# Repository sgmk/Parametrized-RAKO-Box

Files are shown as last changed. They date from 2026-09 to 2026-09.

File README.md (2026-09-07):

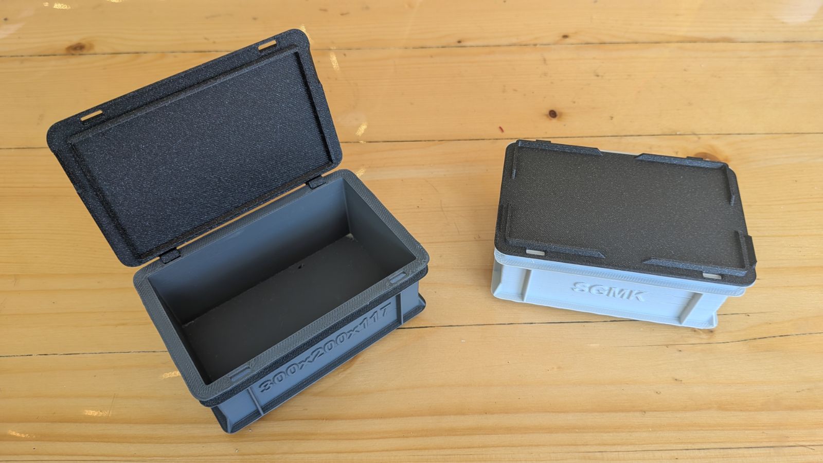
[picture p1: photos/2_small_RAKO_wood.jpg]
Printed Box with Wood Lid


# Parametrized RAKO Box (Eurobox / Stapelbehälter)
A highly customizable, 3D-printable OpenSCAD model of the classic Utz RAKO Eurobox (Stapelbehälter).

This repository contains a fully parametric, printable model that mathematically replicates the complex draft-tapered geometry, structural rims, and stacking feet of a real RAKO box, allowing you to print custom storage solutions that perfectly interlock with industry standards.

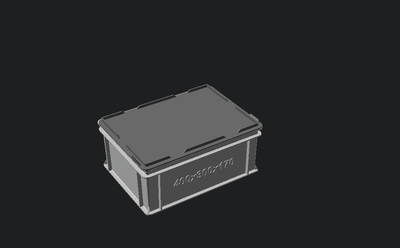
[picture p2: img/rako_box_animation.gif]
Animated Rako Box


## 📖 History of this Project
This project started as an experiment in human-AI collaboration during the [ddoS (das dreitägige odenwilusenz Sommerfest) event](https://ddos.odenwilusenz.ch/Hauptseite) late at night. The goal was to collaborate with an AI assistant to reverse-engineer and parametrically design a highly complex, 3D-printable replica of the classic Utz RAKO Eurobox.

Using a combination of reference photos, official Utz technical catalogs, and even audio messages to describe the intricate physical details (like the continuous draft taper, horizontal rims, and corner gussets), we iteratively refined the model. The entire geometry was coded from scratch in **OpenSCAD**, guided by continuous back-and-forth feedback with **Gemini AI**. Over the course of the night, we went from struggling with basic proportions to mathematically deriving a robust, parametric, support-free printing framework that accurately replicates the authentic industrial design.

## 📸 Gallery
### Real Prints
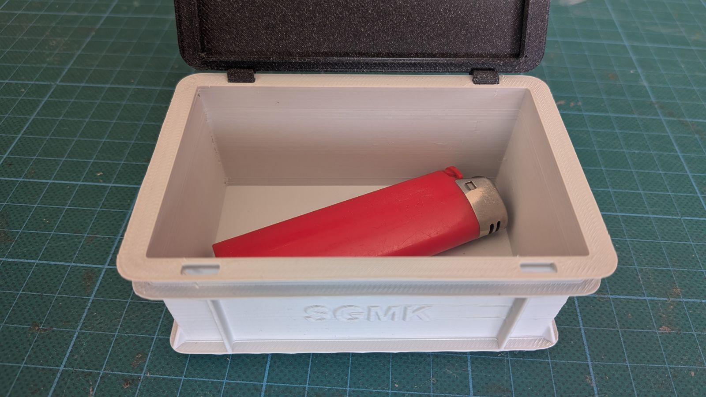
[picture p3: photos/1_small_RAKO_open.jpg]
Printed Box Open

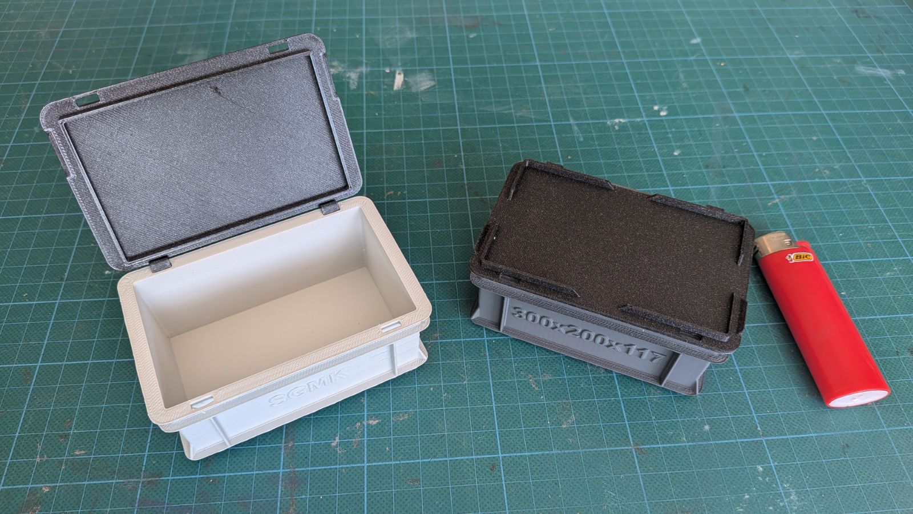
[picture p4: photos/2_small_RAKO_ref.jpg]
Printed Box Reference


### Technical Drawings
*The structural complexity of the RAKO system is derived from its continuous draft taper and nested inset tiers. The outer shell, inner ribs, and bottom stacking foot each reside on precise inward-leaning planes to ensure immense rigidity while allowing identical boxes to interlock seamlessly with a perfect 1mm tolerance. Note that while this model replicates the authentic stacking geometry, the exact wall thicknesses and rib dimensions have been optimized for FDM 3D printing and structural stability, rather than being a 1:1 identical copy of the original injection-molded box.*

<p align="center">
  Overall Cross-Section
  Detailed Wall Cross-Section
</p>

### OpenSCAD Customizer Renders
*(Large size presets shown with Snap-on Lids)*
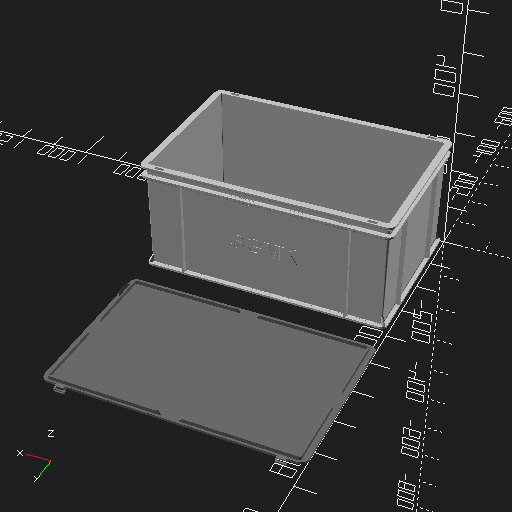
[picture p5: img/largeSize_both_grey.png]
Large Size


## 🆕 What's New in V5
* **Living-Hinge Snap Clips**: The lid now features flexible drop-down snap clips that mechanically lock into the existing side zip-tie holes of the box. The thickness of the clip dynamically calculates to fill the hole depth perfectly for a snug fit.
* **Independent Lid Thickness**: The lid plate thickness has been decoupled from the main wall thickness, allowing you to make much thicker, more robust lids without having to unnecessarily bulk up the box walls.
* **Refined Bash Exporting**: Included bash script now perfectly batch exports standard configurations, completely stripping OpenSCAD parameter overrides.

## ✨ Features
* **Standard & Custom Sizes**: Use the built-in dropdowns to instantly select all standard Utz RAKO footprint sizes (200x150, 300x200, 400x300, 600x400, 800x600) and standard heights, or disable it to enter fully custom L x W x H bounds.
* **Mathematical Stacking**: The model automatically calculates wall thicknesses and dynamic inset steps to guarantee a perfect 1.0mm clearance stacking fit. The boxes will interlock tightly with each other and with real commercial Euroboxes.
* **Support-Free Printing**: The top rims feature parametric diagonal support triangles and massive corner gussets tuned to a standard 50° overhang, allowing you to print the complex upper structural flanges entirely without slicer supports.
* **Snap-Fit Lid & Hinges**: Optional snap-fit interlocking lids, including deep hinge slots on the back edge to attach C-hinges without losing the beautifully rounded corners.
* **Custom Embossing**: Easily emboss your own text labels onto the front and back long sides of the box using any font installed on your system.

## 🖨️ 3D Printing Tips
* **Support Triangles**: Real Utz RAKO boxes don't have small triangular supports under the top rim. However, because FDM 3D printers struggle with aggressive 90-degree overhangs, this parametric model introduces optional support triangles. Leave these enabled in the Customizer to allow the box to print cleanly without needing any slicer-generated support material!
* **Bottom Rim Supports**: While the top rims print support-free, it is highly recommended to enable standard slicer supports for the absolute bottom stacking foot/rim. These supports are very easy to remove and ensure the underside prints with perfect dimensional accuracy, guaranteeing the foot clicks cleanly inside the box below it when stacked.

<p align="center">
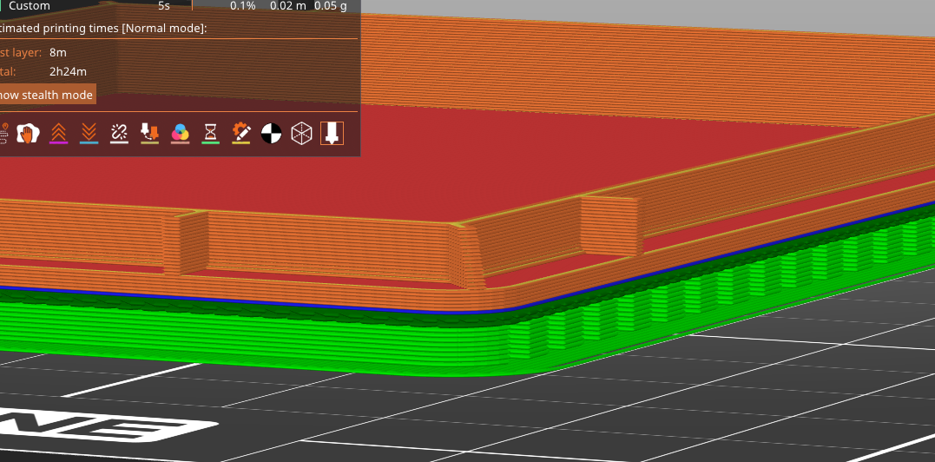
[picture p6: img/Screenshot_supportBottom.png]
Bottom Supports in Slicer
  
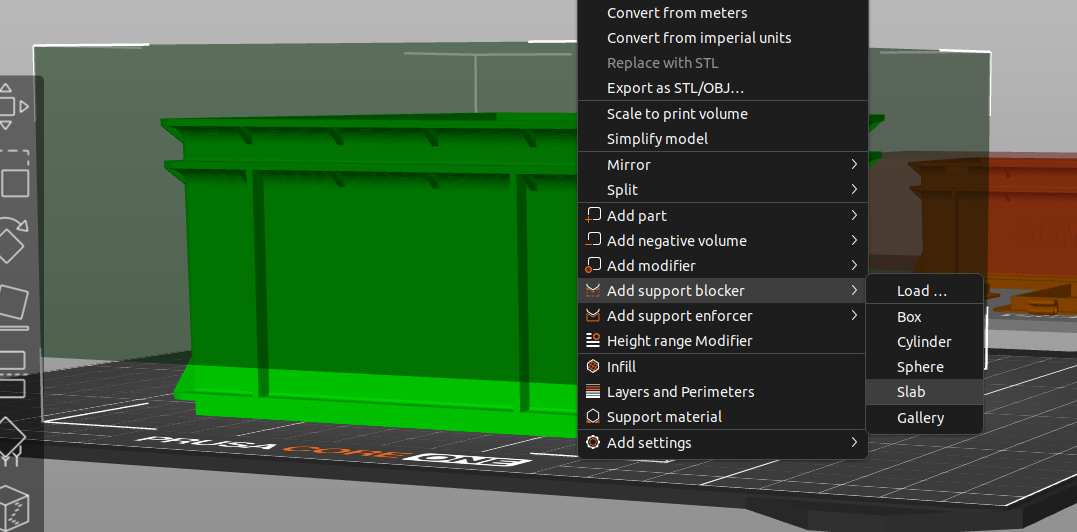
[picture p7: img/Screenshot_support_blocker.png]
Support Blocker in Slicer
  
</p>

* **Support Blockers**: To ensure your slicer only generates supports for the bottom rim and doesn't accidentally try to support the embossed text or the upper support-free rims, add a large support blocker volume (cube) covering the entire upper half of the box.

* **Scaling the Model**: The OpenSCAD design is scaled 1:1 to the exact size and proportions of commercial RAKO boxes. However, **we strongly advise against printing them at full scale!** Printing a full-size RAKO box is an immense waste of time, energy, and PLA—if you need a full-size box, it makes much more sense for the environment (and your wallet) to just buy a real injection-molded one! Instead, this model is meant to be scaled down in your slicer to create perfect miniature organizers. Scaling the generated STLs down to **33%** in your slicer is the sweet spot. At 33%, the snap-fit hinges still function perfectly. You can scale them down to **25%** because they look incredibly cute, but be warned that the hinges will be at the absolute limit of their mechanical stability and may become too fragile!

## 🚀 Usage
1. Place both `rako_box_V5.scad` and the accompanying `rako_box_V5.json` presets file in the same folder.
2. Open the `.scad` file in **OpenSCAD**.
3. Ensure the Customizer is visible (View -> Customizer).
4. Use the dropdowns to configure your box, or select one of the pre-configured presets from the top dropdown (smallSize, midSize, largeSize, BrushologyBox).
5. Render (`F6`) and Export to STL!

### Automated Exporting & Scaling
We have included a handy bash script (`export_stls.sh`) to automatically generate all STLs (the main boxes and the split lids) for the standard presets in one go.

To export everything at 1:1 full scale:
```bash
bash export_stls.sh
```

**Targeting a Single Preset:**
If you only want to export a specific preset, you can pass its name as the second argument (after the scale factor).
For example, to export only the `BrushologyBox` at 1:1 scale:
```bash
bash export_stls.sh 1.0 BrushologyBox
```

**Auto-Scaling for Miniatures:**
Because we strongly recommend printing miniatures, the script supports an optional scale parameter. It will automatically pass this to OpenSCAD and append the scale to the output filenames, so your 1:1 scale STLs are never accidentally overwritten!

For example, to export all presets pre-scaled to 33%:
```bash
bash export_stls.sh 0.33
```
Or to export *only* the `smallSize` preset at 50%:
```bash
bash export_stls.sh 0.5 smallSize
```
This will generate neatly named files like `STLs/smallSize/smallSize_V5_box_scale0.5.stl`.

*(Note: If you save a new custom preset in the Customizer (for example, named `myCustomBox`), you can simply run `bash export_stls.sh 1.0 myCustomBox` and the script will automatically export it for you!)*

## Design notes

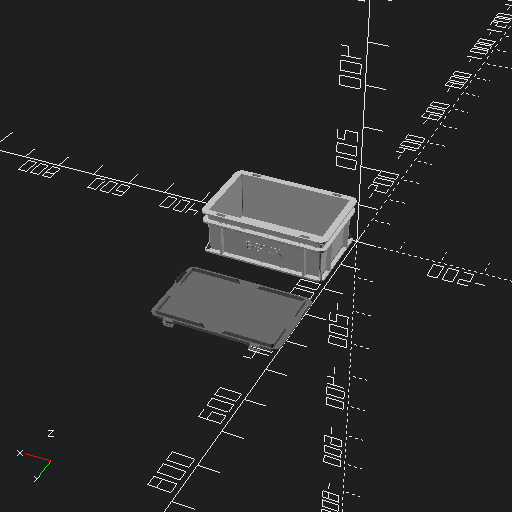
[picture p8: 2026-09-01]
img/smallSize_both_grey.png

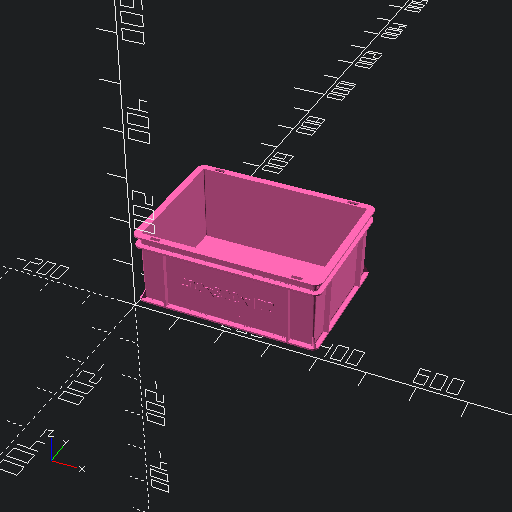
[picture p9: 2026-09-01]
img/midSize.png

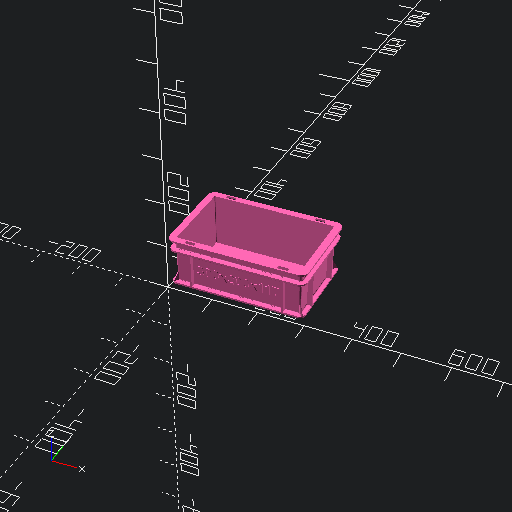
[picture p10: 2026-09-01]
img/smallSize.png

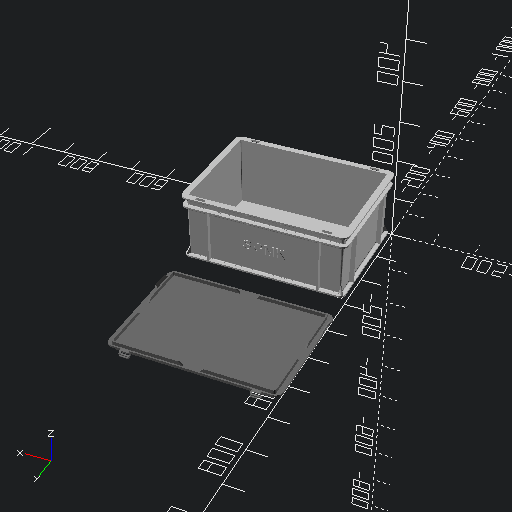
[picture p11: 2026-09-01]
img/midSize_both_grey.png

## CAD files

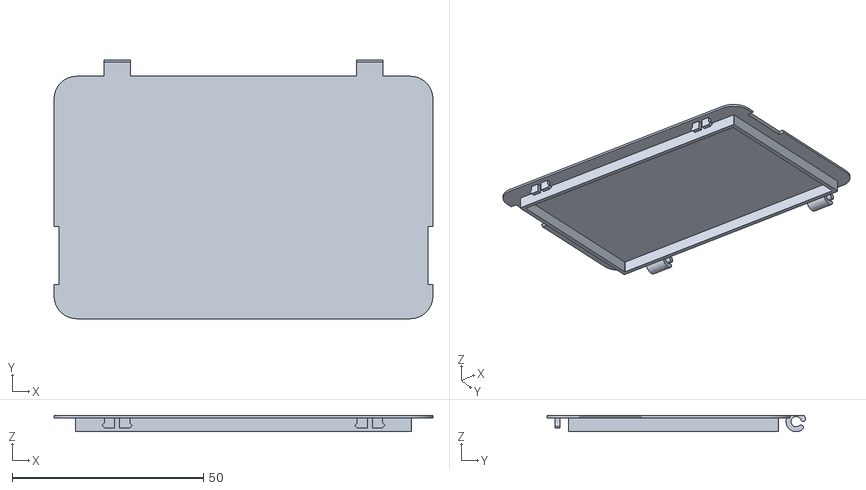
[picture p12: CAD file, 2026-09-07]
STL-Ready4Print/V5/BrushologyBox/BrushologyBox_V5_lid_lower_scale0.33.stl
99.0 x 67.5 x 4.29

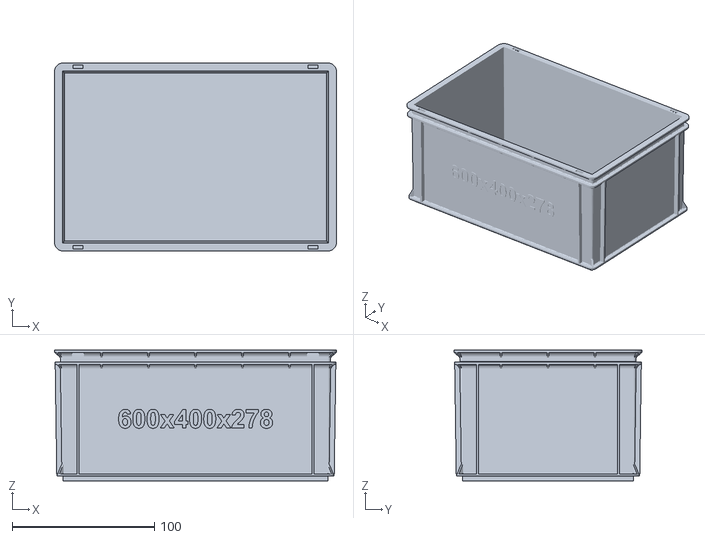
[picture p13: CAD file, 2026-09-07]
STL-Ready4Print/V5/largeSize/largeSize_V5_box_scale0.33.stl
198.0 x 132.0 x 91.7

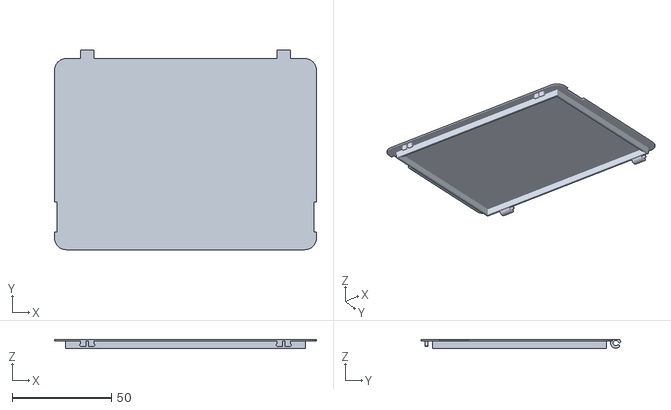
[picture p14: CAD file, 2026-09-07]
STL-Ready4Print/V5/midSize/midSize_V5_lid_lower_scale0.33.stl
132.0 x 100.5 x 4.29

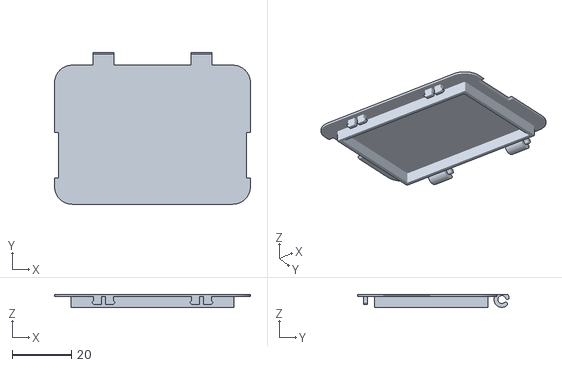
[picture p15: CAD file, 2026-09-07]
STL-Ready4Print/V5/miniSize/miniSize_V5_lid_lower_scale0.33.stl
66.0 x 51.0 x 4.29

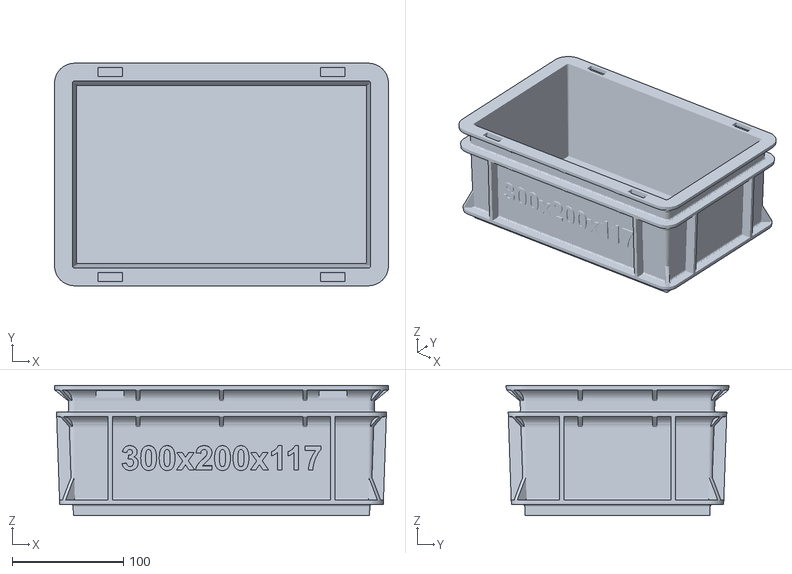
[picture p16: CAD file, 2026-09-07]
STL-Ready4Print/V5/smallSize/smallSize_V5_box.stl
300.0 x 200.0 x 117.0

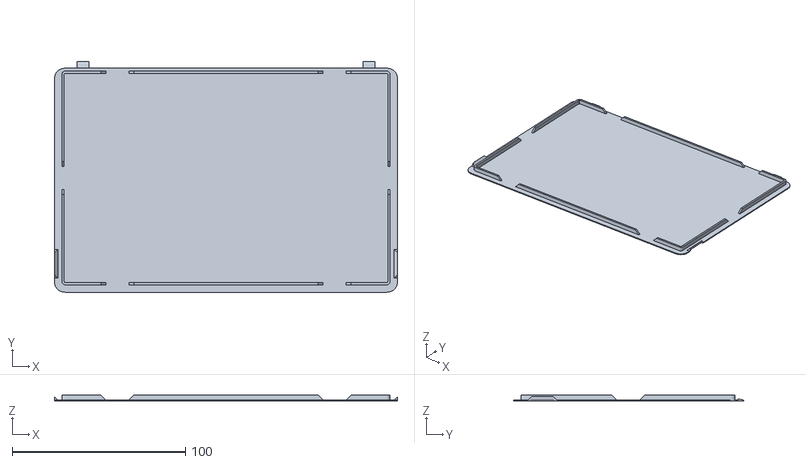
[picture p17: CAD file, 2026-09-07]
STL-Ready4Print/V5/largeSize/largeSize_V5_lid_upper_scale0.33.stl
198.0 x 133.1 x 3.63

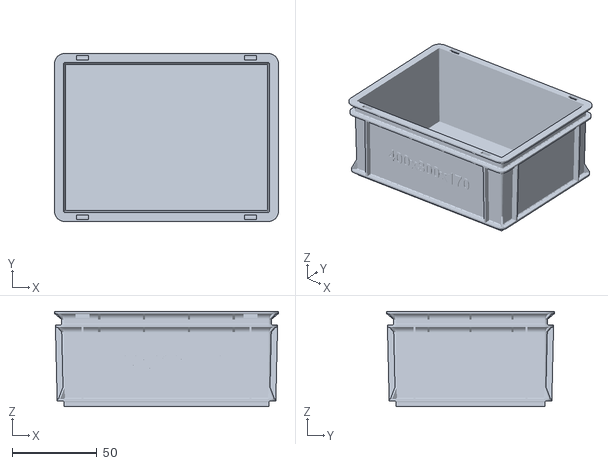
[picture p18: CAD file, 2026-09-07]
STL-Ready4Print/V5/midSize/midSize_V5_box_scale0.33.stl
132.0 x 99.0 x 56.1

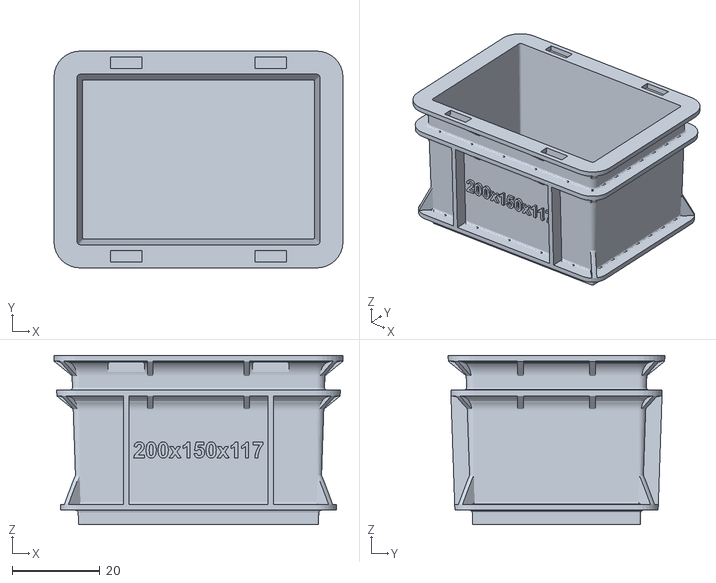
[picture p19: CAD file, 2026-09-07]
STL-Ready4Print/V5/miniSize/miniSize_V5_box_scale0.33.stl
66.0 x 49.5 x 38.6

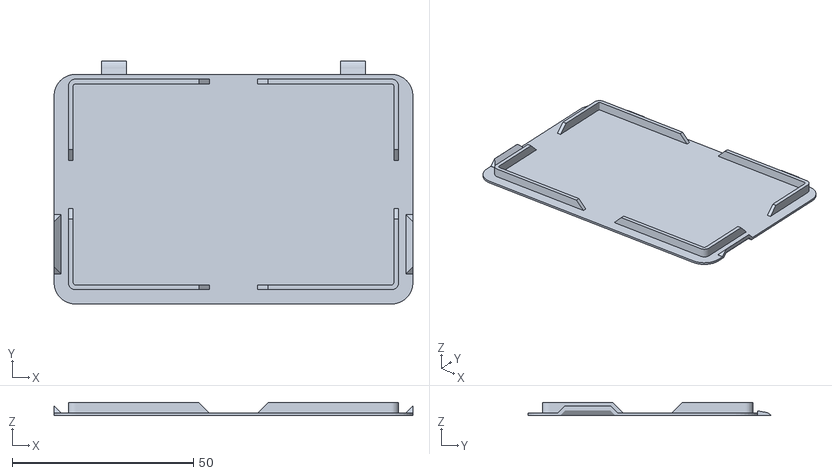
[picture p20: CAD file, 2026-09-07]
STL-Ready4Print/V5/smallSize/smallSize_V5_lid_upper_scale0.33.stl
99.0 x 67.1 x 3.63

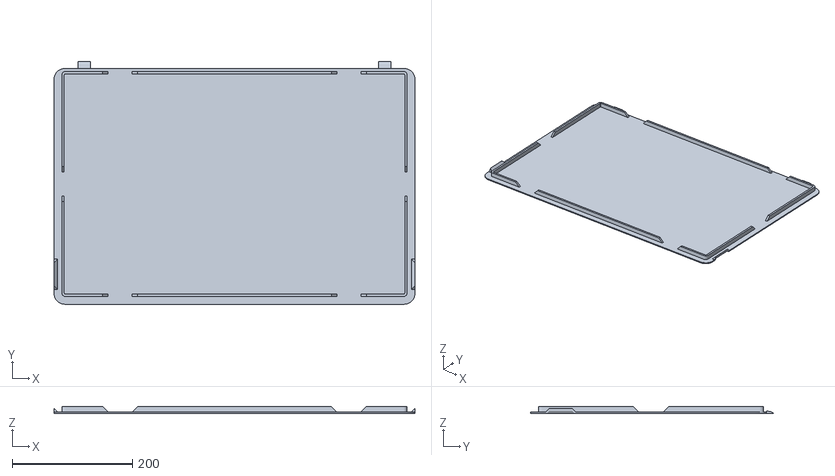
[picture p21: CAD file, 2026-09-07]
STL-Ready4Print/V5/largeSize/largeSize_V5_lid_upper.stl
600.0 x 403.2 x 11.0

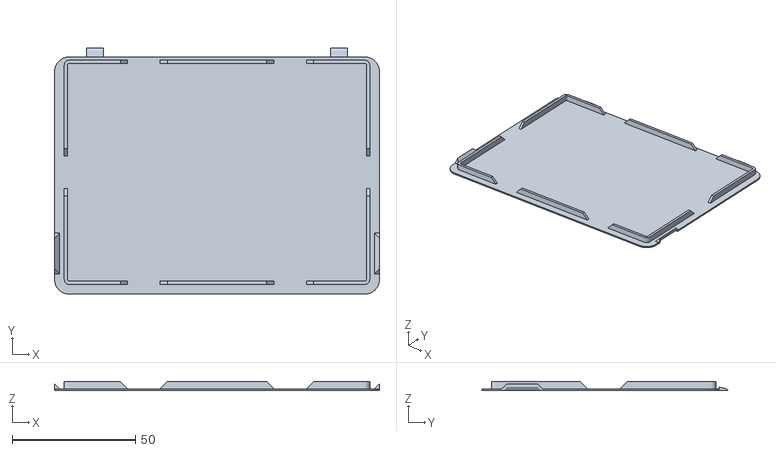
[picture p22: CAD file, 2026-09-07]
STL-Ready4Print/V5/midSize/midSize_V5_lid_upper_scale0.33.stl
132.0 x 100.1 x 3.63

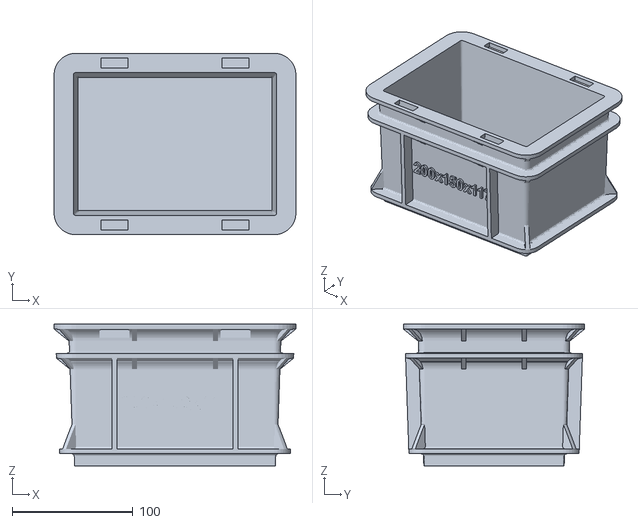
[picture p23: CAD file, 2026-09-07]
STL-Ready4Print/V5/miniSize/miniSize_V5_box.stl
200.0 x 150.0 x 117.0

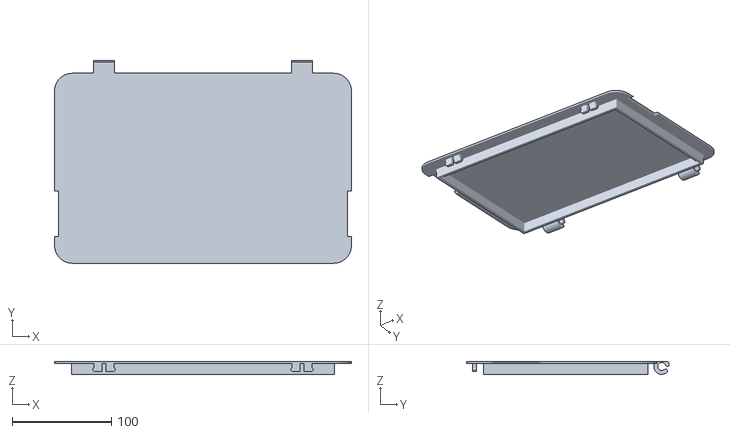
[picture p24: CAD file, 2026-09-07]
STL-Ready4Print/V5/smallSize/smallSize_V5_lid_lower.stl
300.0 x 204.6 x 13.0

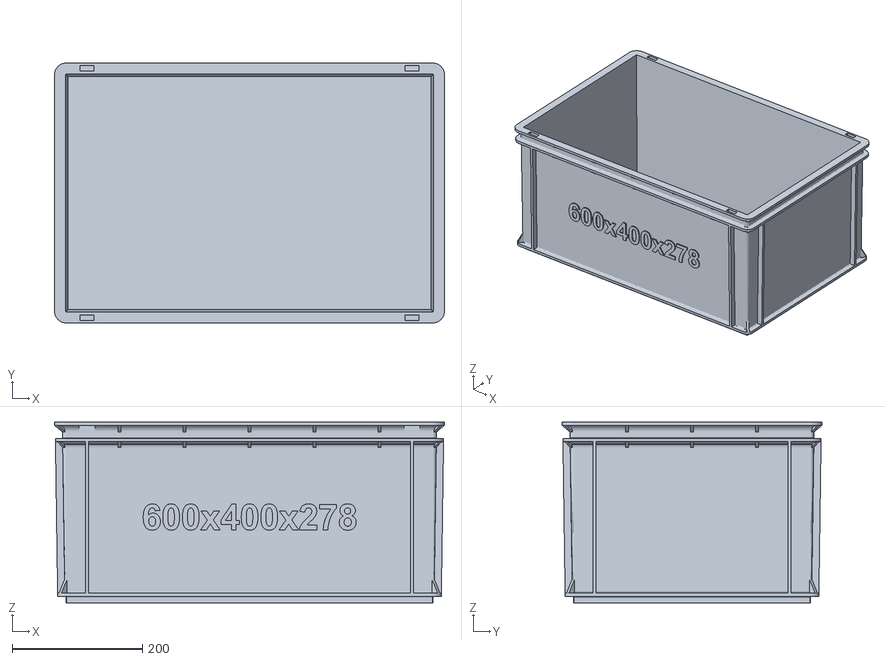
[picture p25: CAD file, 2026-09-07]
STL-Ready4Print/V5/largeSize/largeSize_V5_box.stl
600.0 x 400.0 x 278.0

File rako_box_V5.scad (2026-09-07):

// Parametric Rako Box (Eurobox) - Simplified Edition
// Accurately models the Utz frame construction with a continuous draft angle
// Units in mm
//
// Standard Rako / Eurobox Base Dimensions (L x W):
// - 200 x 150 mm
// - 300 x 200 mm
// - 400 x 300 mm
// - 600 x 400 mm
// - 800 x 600 mm
// 
// Standard Heights (H):
// - 65, 117, 145, 170, 220, 278, 325, 425 mm

// --- User Parameters ---

/* [Render Options] */
// Which part to render
part = "box"; // ["box", "lid", "lid_upper", "lid_lower", "both", "assemble"]
// Height at which to split the lid for 3D printing (creates lid_upper and lid_lower)
lid_split_z = 2.0;

/* [Global Dimensions] */
// Use standard Rako dimensions or custom values below
use_standard_dimensions = true;

// Standard Base Size (L x W)
standard_base = "400x300"; // ["200x150", "300x200", "400x300", "600x400", "800x600"]
// Standard Height
standard_height = 170; // [65, 117, 145, 170, 220, 278, 325, 425]
// Master thickness for all structural rims, flanges, ribs, and main walls
rim_width = 4.0; // [0.1:0.1:8.00]
// Thickness of the main drafted skin walls
wall_thickness = 4.0; // [0.1:0.1:8.00]
// Thickness of the main flat lid plate (wall thickness of the lid)
lid_plate_thickness = 4.0; // [0.1:0.1:8.00]
// Add snap-on C-hinges to the back edge
add_hinges = true;
// Enable the lid closure slots in the top rim
enable_closing_holes = true;

/* [Lid Snap-Fit] */
// Enable mechanical snap-on clips for the lid
add_snap_clips = true;
// Clearance gap between the arm and the box hole
snap_clip_tolerance = 2.0;

/* [Custom Dimensions] */
// (These are only used if 'use_standard_dimensions' is unchecked)
custom_length = 300;
// Custom Width
custom_width = 200;
// Custom Height
custom_height = 117;

/* [3D-Printing Features] */
// Number of small triangular supports evenly spaced under the top rim per side
support_triangles = 4; // [0:10]
// Add corner triangular supports under the top rim
support_corners = true;
// 3D Printing Overhang Angle for the supports (from vertical Z-axis). Higher is a shallower slope, easier to print.
support_angle = 50.0; // [30:70]

/* [Text Options] */
// Text embossed on the front long side
text_front = "400x300x170";
// Text embossed on the back long side
text_back = "SGMK";
// Font style for the text
text_font = "Arial:style=Bold";
// Font size
text_size = 25.0;
// Horizontal offset for the text (moves left/right)
text_x_offset = 0.0;
// Vertical offset for the text (moves up/down)
text_z_offset = 0.0;
// How far the embossed text protrudes outwards or inwards from the wall
text_thickness = 2.0;
// Whether the text should stick outwards (embossed) or cut inwards (debossed)
text_emboss_style = "outwards"; // ["outwards", "inwards"]
// Where the text is vertically centered. "auto" centers across the whole height for boxes <= threshold.
text_placement = "auto"; // ["auto", "main_wall", "full_height"]
// If text_placement is "auto", boxes with height <= this threshold will use "full_height" placement
text_auto_threshold = 65.0; 

/* [Appearance] */
// The color of the rendered box in OpenSCAD
box_color = "HotPink"; // ["DimGray": Dark Grey, "Silver": Light Grey, "FireBrick": Red, "HotPink": Hot Pink, "SteelBlue": Blue, "DarkGreen": Green, "Goldenrod": Yellow, "Black": Black, "White": White]
// The color of the rendered lid in OpenSCAD
lid_color = "SteelBlue"; // ["DimGray": Dark Grey, "Silver": Light Grey, "FireBrick": Red, "HotPink": Hot Pink, "SteelBlue": Blue, "DarkGreen": Green, "Goldenrod": Yellow, "Black": Black, "White": White]
// ==============================================================================
// --- Hidden / Advanced Parameters ---
// Everything below this line is hidden from the Customizer to keep it simple!
module __Customizer_Limit__(){}
// ==============================================================================

// Global scaling factor for the rendered part (used by export scripts to create miniatures)
export_scale = 1.0;

// Derived Dimensions from the toggle
length =
  use_standard_dimensions ?
    (
      standard_base == "200x150" ? 200
      : standard_base == "300x200" ? 300
      : standard_base == "400x300" ? 400
      : standard_base == "600x400" ? 600 : 800
    )
  : custom_length;

width =
  use_standard_dimensions ?
    (
      standard_base == "200x150" ? 150
      : standard_base == "300x200" ? 200
      : standard_base == "400x300" ? 300
      : standard_base == "600x400" ? 400 : 600
    )
  : custom_width;

height = use_standard_dimensions ? standard_height : custom_height;

// Global draft taper: how much the entire box leans inwards towards the bottom per side (creates the stacking angle)
draft_amt = 4.0;
// Base corner radius of the absolute outer bounding box
corner_r = 18.0;

// Tier 1 (Absolute Outer Bounds): How far in the widest parts sit
inset_t1 = 0.0; // Upper Lip
// Tier 2 (The Frame): How far in the structural framework sits
inset_t2 = 1.0; // Lower lip, Bottom flange, Vertical Ribs
// Tier 3 (The Skin): How far in the main thin walls sit
inset_t3 = 12.0; // Main Wall, Top Rim Groove

// Height of the stacking foot at the very bottom (fits inside the box below it)
h_foot = 10.0;
// Height of the structural bottom flange
h_flange_bot = rim_width;
// Height of the triangular corner gussets (mini ribs) at the bottom corners
h_gusset = 20.0;

// Height of the structural lower flange of the top rim
h_flange_top = (height <= 65) ? 0 : rim_width;
// Height of the recessed groove in the top rim
h_groove = 20.0;
// Height of the absolute upper lip at the top rim
h_lip = rim_width;

// Thickness of the absolute bottom floor of the box
t_bottom = rim_width;

// (Moved to customizer)
// Thickness of the rims and ridges on the lid
lid_rim_thickness = 4.0;
// Height of the stacking rims on top of the lid
lid_rim_h_top = 9.0;
// Height of the inner alignment skirt dropping into the box
lid_rim_h_bot = 11.0;
// The size of the gap in the middle of the lid rims
lid_gap_size = 40.0;
// Distance of the lid stacking rim breaks from the corners (only applies to boxes >= 400mm)
lid_gap_dist_from_corner =110.0;
// Length of the side lifting handles
lid_handle_len = 50.0;
// Distance from the front edge to the center of the side handles
lid_handle_pos = 50.0;
// Height of the side lifting handles (typically less than the rim)
lid_handle_h = 6.0;

// Thickness of the C-hinge plastic
hinge_thickness = 8.0;
// How far the back edge of the lid is cut inwards to make room for hinges
hinge_cutout_depth = 8.0;
// Position of the hinge inwards from the absolute outer edge of the box
hinge_y_offset = 3.0;
// Vertical position of the hinge center (0 = flush with top of box rim)
hinge_z_offset = -3.0;
// Inner diameter of the C-clip (matches the pin it snaps onto)
hinge_inner_diameter = 8.0;

// Radius of the supportive fillet curve underneath the bottom rim
fillet_bot_r = 2.0;
// Radius of the supportive fillet curves underneath the top rim's flanges
fillet_top_r = 10.0;
// Radius of the smoothing fillet curves on the upper top-side of the horizontal rims
fillet_upper_r = 2.0;

// Width/Size of the corner triangle masks (controls how wide the bottom corner gussets spread)
corner_w = 40.0;
// Thickness of the vertical structural ribs
rib_w = rim_width;
// Distance of the vertical ribs from the corners (fixed mm distance)
rib_dist_from_corner = 50.0;

// The width of the rectangular closure slots
hole_width = 22.0;
// How far the slot cuts inwards (Y depth) into the upper rim plastic
hole_depth = 8.0;
// How far the slots are positioned away from the corners
hole_dist_from_corner = 50.0;
// How far the slots are inset from the absolute outer edge of the upper lip
hole_inset_from_edge = 4.0;

eps = 0.05;

// --- Derived Dimensions (Do not edit) ---
t_rim = inset_t3 + wall_thickness; // Main cavity inset based on wall thickness

// For the box to stack, the bottom foot must be smaller than the top cavity.
// The top cavity is inset by `t_rim`. The bottom outer wall is inset by `inset_t3 + draft_amt`.
// If the walls are too thick, we must step the foot further inwards so it still fits!
foot_clearance = 1.0;
foot_inset = inset_t3 + max(0, t_rim - (inset_t3 + draft_amt) + foot_clearance);

// --- Helper Modules ---
module corner_rib_masks() {
  union() {
    // Front-Left
    translate([0, 0, 0]) rotate([0, 0, 45]) translate([0, -rib_w / 2, 0]) cube([corner_w, rib_w, height]);
    // Front-Right
    translate([length, 0, 0]) rotate([0, 0, 135]) translate([0, -rib_w / 2, 0]) cube([corner_w, rib_w, height]);
    // Back-Left
    translate([0, width, 0]) rotate([0, 0, -45]) translate([0, -rib_w / 2, 0]) cube([corner_w, rib_w, height]);
    // Back-Right
    translate([length, width, 0]) rotate([0, 0, -135]) translate([0, -rib_w / 2, 0]) cube([corner_w, rib_w, height]);
  }
}
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

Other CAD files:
STL-Ready4Print/V5/BrushologyBox/BrushologyBox_V5_lid_upper.stl
STL-Ready4Print/V5/BrushologyBox/BrushologyBox_V5_box.stl
STL-Ready4Print/V5/BrushologyBox/BrushologyBox_V5_lid_lower.stl
STL-Ready4Print/V5/midSize/midSize_V5_box.stl
rako_box_V4.scad
older_versions/rako_box_V4.scad
STL-Ready4Print/V4/ArduinoBox-mini/ArduinoBox-mini_box_scale0.33.stl
STL-Ready4Print/V4/ArduinoBox-mini/ArduinoBox-mini_lid_lower_scale0.33.stl
STL-Ready4Print/V4/ArduinoBox-mini/ArduinoBox-mini_lid_upper_scale0.33.stl
STL-Ready4Print/V4/largeSize/largeSize_box.stl
STL-Ready4Print/V4/largeSize/largeSize_box_scale0.33.stl
STL-Ready4Print/V4/largeSize/largeSize_lid_lower.stl
STL-Ready4Print/V4/largeSize/largeSize_lid_lower_scale0.33.stl
STL-Ready4Print/V4/largeSize/largeSize_lid_upper.stl
STL-Ready4Print/V4/largeSize/largeSize_lid_upper_scale0.33.stl
STL-Ready4Print/V4/midSize/midSize_box.stl
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

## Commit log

2026-09-01 first complete release
    [box.stl, lid_lower.stl, lid_upper.stl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]
2026-09-01 added tech drawings
    [rako_box_V4.scad]
2026-09-01 re-exported all files
    [box.stl, lid_lower.stl, lid_upper.stl]
2026-09-01 re-exported and added mini arduino boxes
    [ArduinoBox-mini_box_scale0.33.stl, ArduinoBox-mini_lid_lower_scale0.33.stl, ArduinoBox-mini_lid_upper_scale0.33.stl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]
2026-09-07 V5 release with click in lid
    [ArduinoBox-mini_box_scale0.33.stl, ArduinoBox-mini_lid_lower_scale0.33.stl, ArduinoBox-mini_lid_upper_scale0.33.stl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]
